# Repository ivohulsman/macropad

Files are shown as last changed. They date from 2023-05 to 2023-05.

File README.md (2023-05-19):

# Macropad V1
A Macropad built with KMK firmware.

**This is a work in progress.**  

### How to install firmware
1. Follow the KMK guide as shown [here](http://kmkfw.io/docs/Getting_Started).
2. Copy the files from /src to your Macropad overwriting existing files.
3. Customize keymaps and OLED to your usecase.

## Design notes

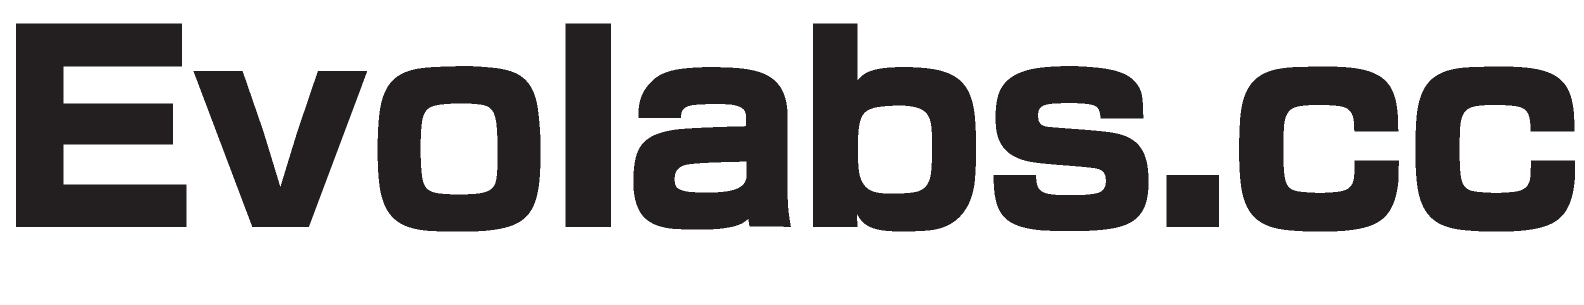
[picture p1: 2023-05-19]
pcb/assets/macropad_evolabs.bmp

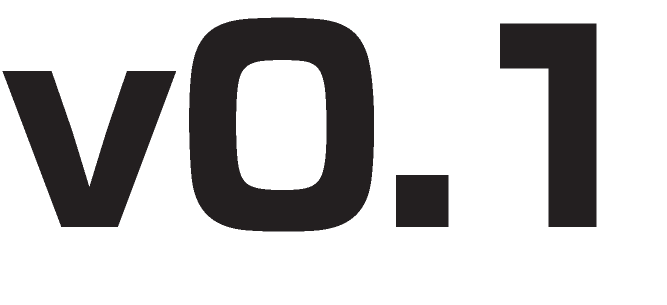
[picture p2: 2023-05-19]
pcb/assets/macropad_version.bmp

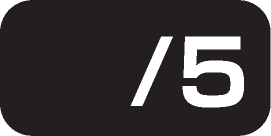
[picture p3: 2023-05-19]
pcb/assets/macropad_sn.bmp

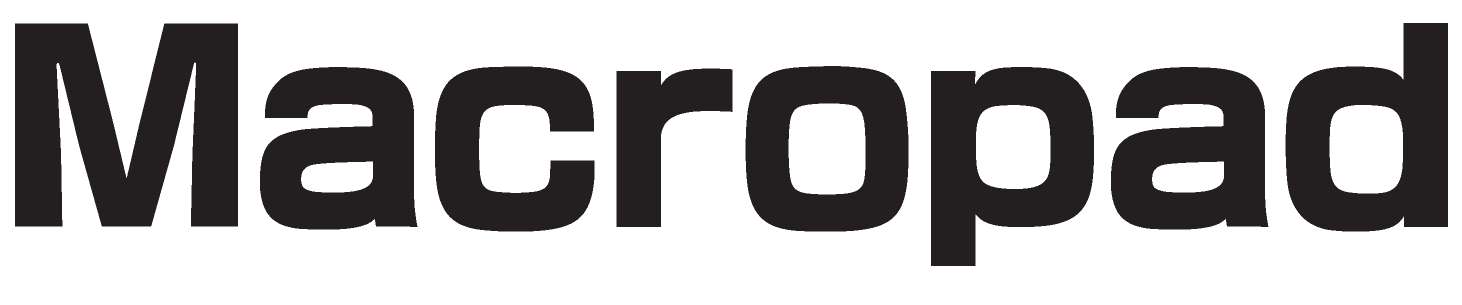
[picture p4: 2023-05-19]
pcb/assets/macropad_v0-1.bmp

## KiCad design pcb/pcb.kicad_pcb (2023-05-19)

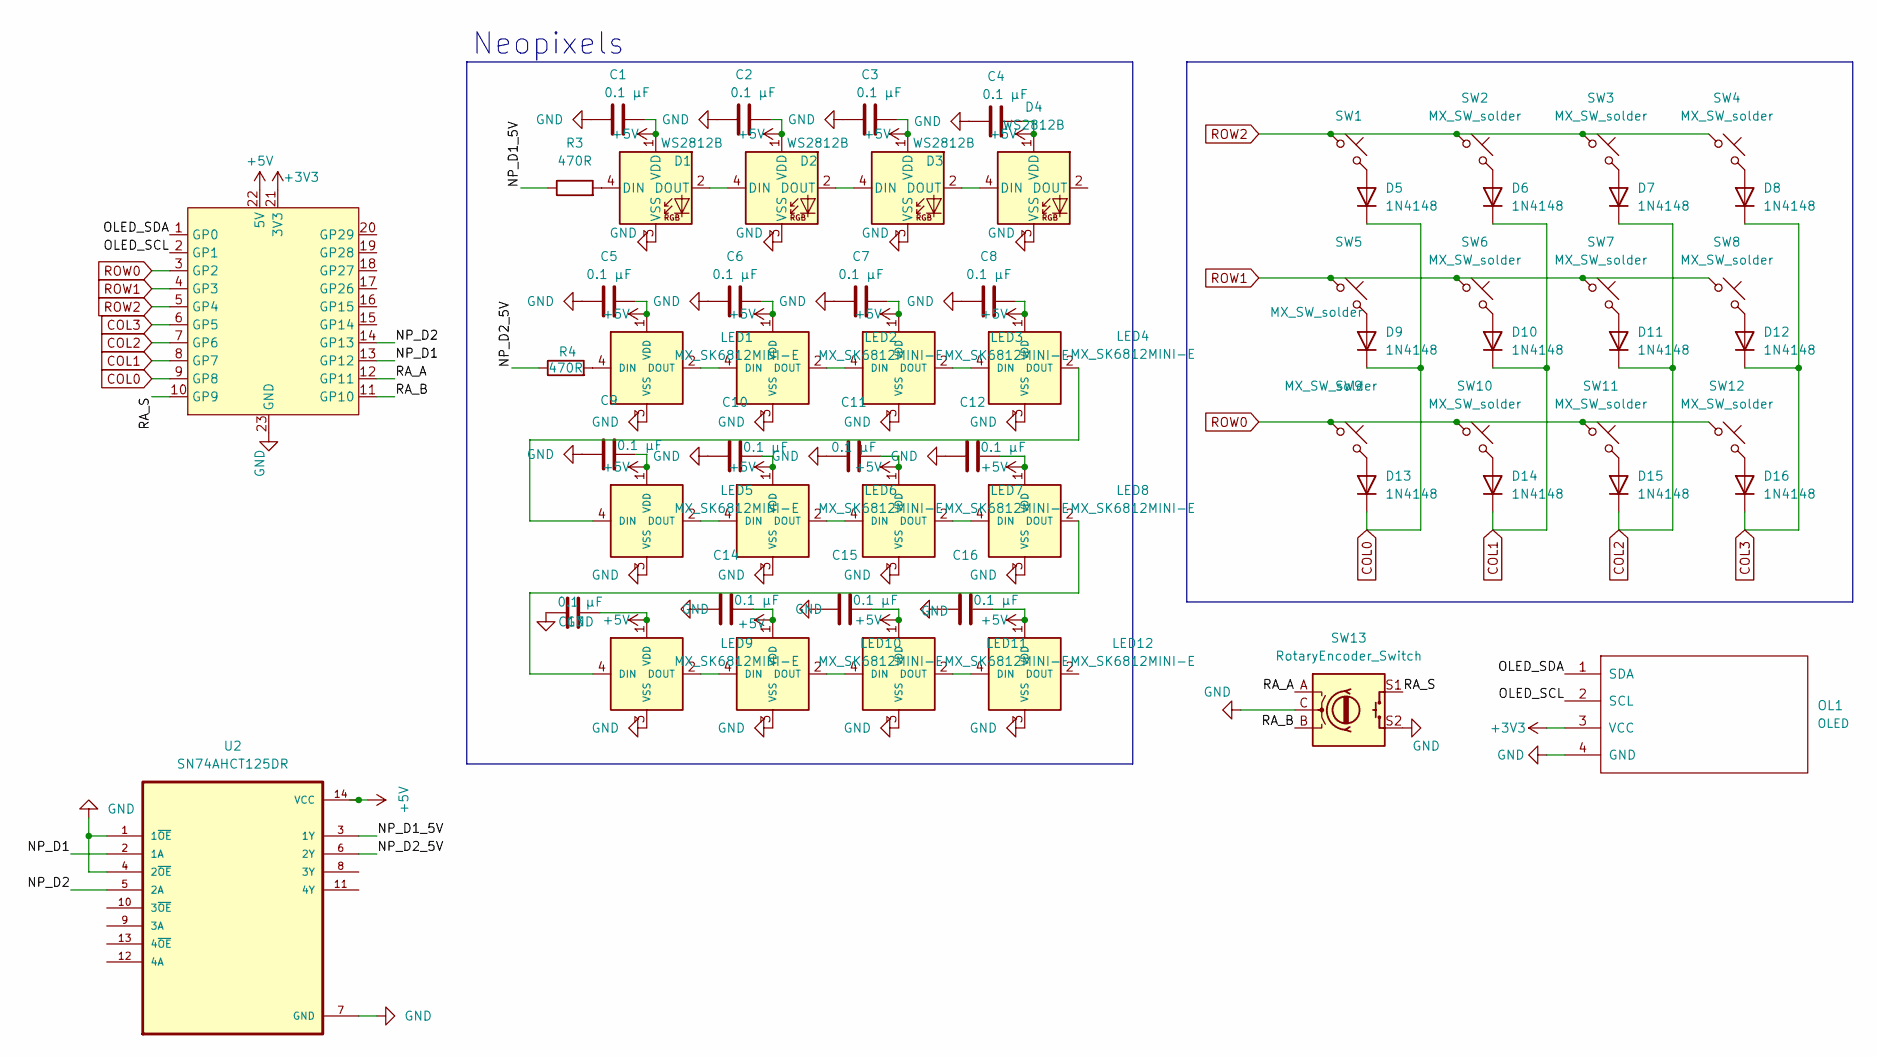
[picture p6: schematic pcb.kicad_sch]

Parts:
C1, C2, C3, C4, C5, C6, C7, C8, C9, C10, C11, C12, C13, C14, C15, C16: 0.1 µF; C_0603_1608Metric
D1, D2, D3, D4: WS2812B; LED_WS2812B_PLCC4_5.0x5.0mm_P3.2mm
D5, D6, D7, D8, D9, D10, D11, D12, D13, D14, D15, D16: 1N4148; D_DO-35_SOD27_P7.62mm_Horizontal
LED1, LED2, LED3, LED4, LED5, LED6, LED7, LED8, LED9, LED10, LED11, LED12: MX_SK6812MINI-E; SK6812-MINI-E
OL1: OLED; SSD1306_0.96_Oled
R3, R4: 470R; R_0603_1608Metric
SW1, SW2, SW3, SW4, SW5, SW6, SW7, SW8, SW9, SW10, SW11, SW12: MX_SW_solder; MX_ALPS_PG1350_noLed
SW13: RotaryEncoder_Switch; RotaryEncoder_EC11
U1: PicoW; RP2040-Zero
U2: SN74AHCT125DR; SOIC127P600X175-14N

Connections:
+3V3: OL1.3 (VCC), U1.21 (3V3)
+5V: C1.2, C2.2, C3.2, C4.2, C5.2, C6.2, C7.2, C8.2, C9.2, C10.2, C11.2, C12.2, C13.2, C14.2, C15.2, C16.2, D1.1 (VDD), D2.1 (VDD), D3.1 (VDD), D4.1 (VDD), LED1.1 (VDD), LED2.1 (VDD), LED3.1 (VDD), LED4.1 (VDD), LED5.1 (VDD), LED6.1 (VDD), LED7.1 (VDD), LED8.1 (VDD), LED9.1 (VDD), LED10.1 (VDD), LED11.1 (VDD), LED12.1 (VDD), U1.22 (5V), U2.14 (VCC)
/NP_D1: U1.13 (GP12), U2.2 (1A)
/NP_D1_5V: R3.1, U2.3 (1Y)
/NP_D2: U1.14 (GP13), U2.5 (2A)
/NP_D2_5V: R4.1, U2.6 (2Y)
/OLED_SCL: OL1.2 (SCL), U1.2 (GP1)
/OLED_SDA: OL1.1 (SDA), U1.1 (GP0)
/RA_A: SW13.A, U1.12 (GP11)
/RA_B: SW13.B, U1.11 (GP10)
/RA_S: SW13.S1, U1.10 (GP9)
COL0: D5.1 (K), D9.1 (K), D13.1 (K), U1.9 (GP8)
COL1: D6.1 (K), D10.1 (K), D14.1 (K), U1.8 (GP7)
COL2: D7.1 (K), D11.1 (K), D15.1 (K), U1.7 (GP6)
COL3: D8.1 (K), D12.1 (K), D16.1 (K), U1.6 (GP5)
GND: C1.1, C2.1, C3.1, C4.1, C5.1, C6.1, C7.1, C8.1, C9.1, C10.1, C11.1, C12.1, C13.1, C14.1, C15.1, C16.1, D1.3 (VSS), D2.3 (VSS), D3.3 (VSS), D4.3 (VSS), LED1.3 (VSS), LED2.3 (VSS), LED3.3 (VSS), LED4.3 (VSS), LED5.3 (VSS), LED6.3 (VSS), LED7.3 (VSS), LED8.3 (VSS), LED9.3 (VSS), LED10.3 (VSS), LED11.3 (VSS), LED12.3 (VSS), OL1.4 (GND), SW13.C, SW13.S2, U1.23 (GND), U2.1 (1~OE), U2.4 (2~OE), U2.7 (GND)
unnamed: D1.4 (DIN), R3.2
unnamed: D1.2 (DOUT), D2.4 (DIN)
unnamed: D2.2 (DOUT), D3.4 (DIN)
unnamed: D3.2 (DOUT), D4.4 (DIN)
unnamed: D5.2 (A), SW1.2
unnamed: D6.2 (A), SW2.2
unnamed: D7.2 (A), SW3.2
unnamed: D8.2 (A), SW4.2
unnamed: D9.2 (A), SW5.2
unnamed: D10.2 (A), SW6.2
unnamed: D11.2 (A), SW7.2
unnamed: D12.2 (A), SW8.2
unnamed: D13.2 (A), SW9.2
unnamed: D14.2 (A), SW10.2
unnamed: D15.2 (A), SW11.2
unnamed: D16.2 (A), SW12.2
unnamed: LED1.4 (DIN), R4.2
unnamed: LED1.2 (DOUT), LED2.4 (DIN)
unnamed: LED2.2 (DOUT), LED3.4 (DIN)
unnamed: LED3.2 (DOUT), LED4.4 (DIN)
unnamed: LED4.2 (DOUT), LED5.4 (DIN)
unnamed: LED5.2 (DOUT), LED6.4 (DIN)
unnamed: LED6.2 (DOUT), LED7.4 (DIN)
unnamed: LED7.2 (DOUT), LED8.4 (DIN)
unnamed: LED8.2 (DOUT), LED9.4 (DIN)
unnamed: LED9.2 (DOUT), LED10.4 (DIN)
unnamed: LED10.2 (DOUT), LED11.4 (DIN)
unnamed: LED11.2 (DOUT), LED12.4 (DIN)
ROW0: SW9.1, SW10.1, SW11.1, SW12.1, U1.3 (GP2)
ROW1: SW5.1, SW6.1, SW7.1, SW8.1, U1.4 (GP3)
ROW2: SW1.1, SW2.1, SW3.1, SW4.1, U1.5 (GP4)

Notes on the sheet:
Neopixels

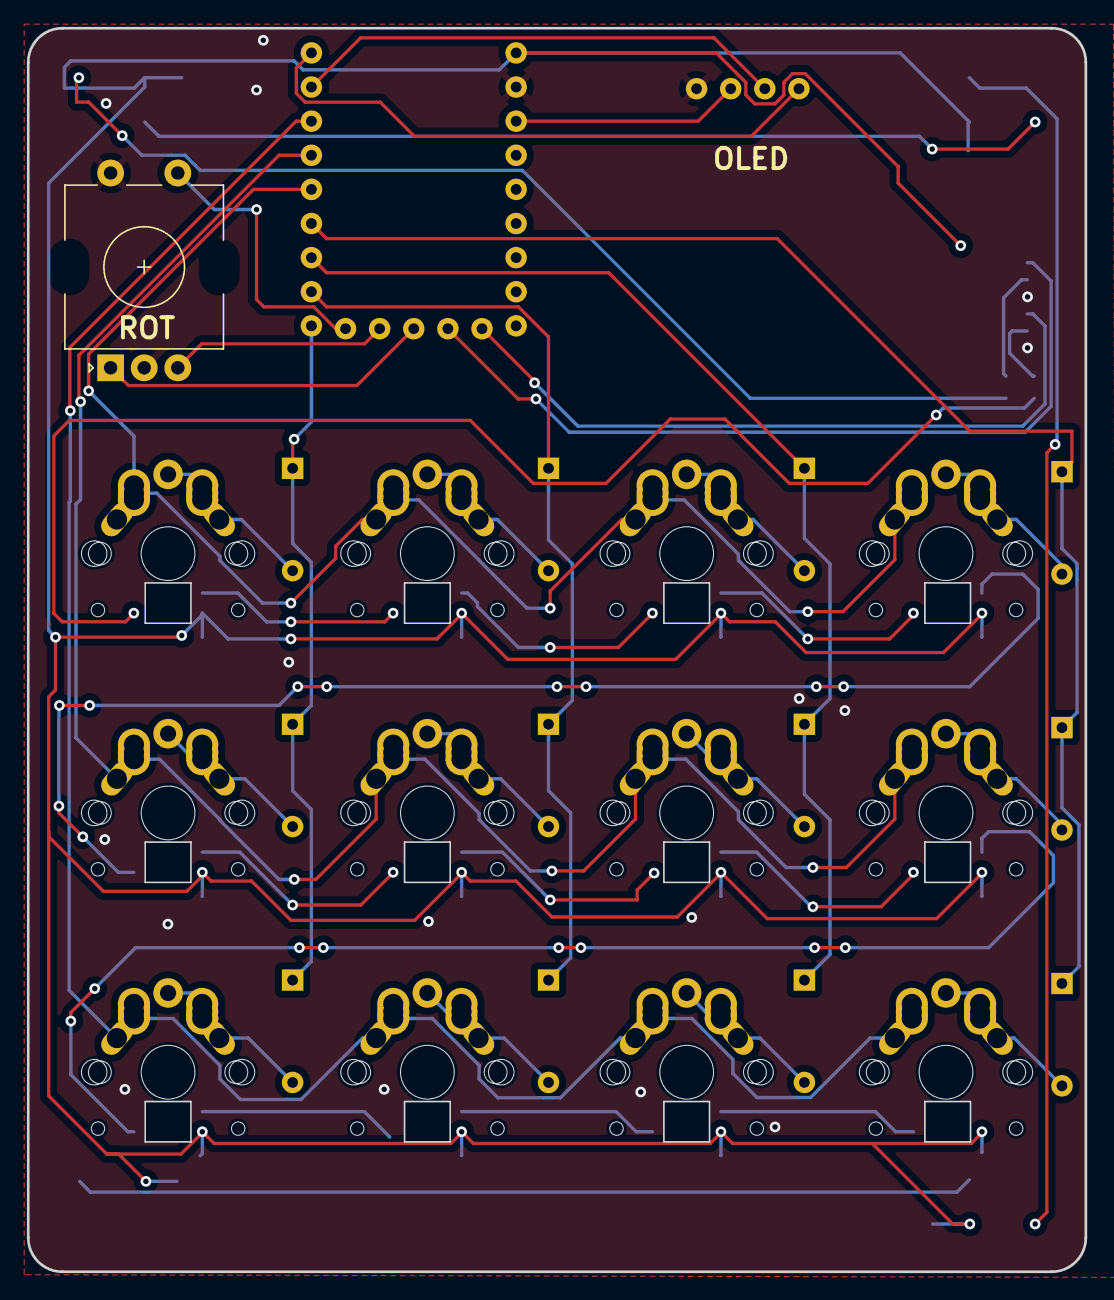
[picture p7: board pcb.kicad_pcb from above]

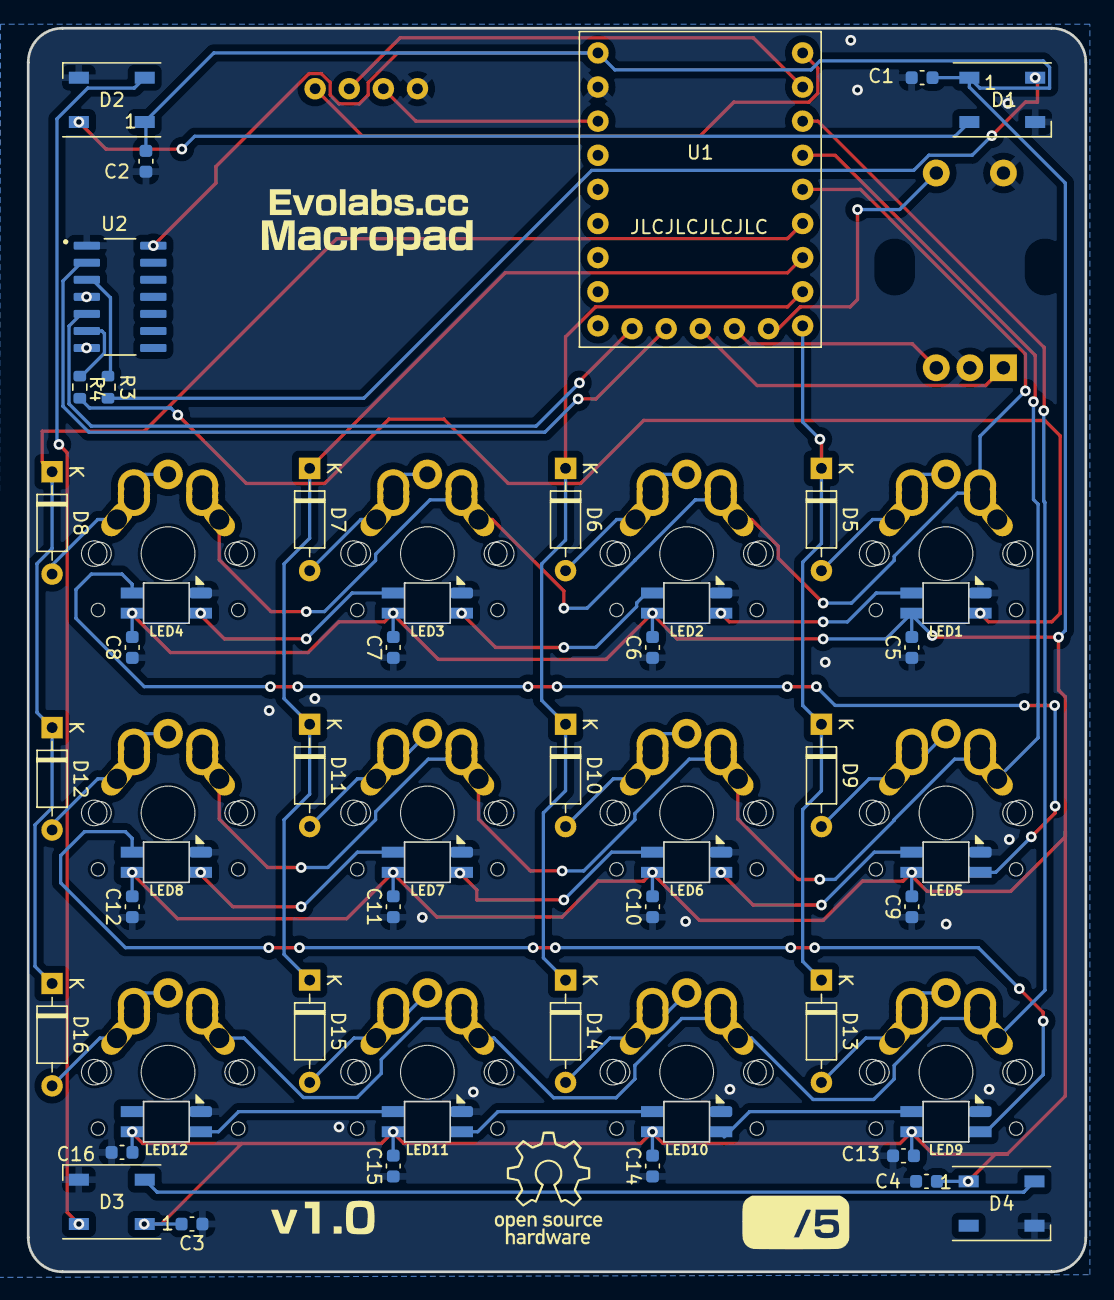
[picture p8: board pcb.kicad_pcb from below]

Board: 2 copper layers, 78.7 x 92.6 mm, 62 parts (49 on the bottom side), 47 nets.

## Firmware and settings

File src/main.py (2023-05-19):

from kb import KMKKeyboard

import supervisor

from kmk.extensions.media_keys import MediaKeys
from kmk.keys import KC
from kmk.modules.encoder import EncoderHandler
from kmk.modules.layers import Layers
from kmk.modules.modtap import ModTap
from kmk.handlers.sequences import simple_key_sequence


# Disable hot reloading on save
supervisor.runtime.autoreload = True


keyboard = KMKKeyboard()
layers = Layers()
modtap = ModTap()

# Debug mode
keyboard.debug_enabled = False

# Append extensions to KMK
keyboard.extensions.append(keyboard.rgb)
keyboard.extensions.append(MediaKeys())
keyboard.extensions.append(keyboard.oled)


# Init Rotary Encoder
encoder_handler = EncoderHandler()
encoder_handler.pins = (
    (keyboard.rot_a_pin, keyboard.rot_b_pin,
     keyboard.rot_bt_pin, False, 4),  # encoder #1
)

keyboard.modules = [layers, encoder_handler, modtap]

# Define layers
LYR_NOR, LYR_RGB, LYR_MOD = 0, 1, 2

# Define custom keys
MOD_OR_NORM = KC.MT(KC.TO(LYR_NOR), KC.MO(LYR_MOD))

# Save VIM macro
VIM_WBUF = simple_key_sequence(
    (
        KC.ESC,
        KC.COLN,
        KC.W,
        KC.ENTER,
    )
)

# Define Keymaps
keyboard.keymap = [
    [
        # Normal Layer
        KC.A, KC.B, KC.C, KC.D,
        VIM_WBUF, KC.F, KC.G, KC.H,
        KC.I, KC.J, KC.K, MOD_OR_NORM,
    ],
    [
        # RGB Layer
        KC.RGB_VAI, KC.RGB_VAD, KC.RGB_HUI, KC.RGB_HUD,
        KC.RGB_SAI, KC.RGB_SAD, KC.RGB_MODE_PLAIN, KC.RGB_MODE_BREATHE,
        KC.RGB_MODE_RAINBOW, KC.RGB_MODE_BREATHE_RAINBOW, KC.RGB_MODE_SWIRL, KC.MO(
            LYR_MOD),
    ],
    [
        # Mode Layer
        KC.TO(LYR_NOR), KC.B, KC.C, KC.D,
        KC.E, KC.F, KC.G, KC.H,
        KC.TO(LYR_RGB), KC.J, KC.RELOAD, KC.L,
    ]
]

# Define Rotary Encoder Keymaps
encoder_handler.map = [((KC.VOLD, KC.VOLU, KC.MUTE),),  # Standard
                                ((KC.VOLD, KC.VOLU, KC.MUTE),),  # Extra
                                ]

if __name__ == '__main__':
    keyboard.go()

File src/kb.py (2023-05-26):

import os
import board
import busio 
import neopixel

from kmk.kmk_keyboard import KMKKeyboard as _KMKKeyboard
from kmk.scanners import DiodeOrientation
from kmk.extensions.rgb import RGB
from kmk.extensions.oled import Oled, TextEntry, ImageEntry # New OLED extension


class KMKKeyboard(_KMKKeyboard):
    col_pins = (
        board.GP8,
        board.GP7,
        board.GP6,
        board.GP5,
    )

    row_pins = (
        board.GP4,
        board.GP3,
        board.GP2,
    )

    diode_orientation = DiodeOrientation.ROWS

    bl_pin = board.GP13
    ug_pin = board.GP12

    rot_a_pin = board.GP10
    rot_b_pin = board.GP11
    rot_bt_pin = board.GP9

    SCL = board.GP1
    SDA = board.GP0

# Init RGB
    pixels = (
        neopixel.NeoPixel(bl_pin, 12,),
        neopixel.NeoPixel(ug_pin, 4,)
    )

    rgb = RGB(pixel_pin=None, pixels=pixels,
              hue_default=os.getenv("RGB_HUE"),
              sat_default=os.getenv("RGB_SAT"),
              val_default=os.getenv("RGB_BOOT_VAL"),
              val_limit=os.getenv("RGB_VAL"),
              val_step=36)

    oled = Oled(
        entries=[
            TextEntry(text='my', x=128, y=0, x_anchor='R'),
            TextEntry(text='keyboard', x=128, y=10, x_anchor='R'),
            TextEntry(text='left', x=128, y=20, x_anchor='R', side='L'),
            TextEntry(text='right', x=128, y=20, x_anchor='R', side='R'),
            TextEntry(text='Layer: ', x=0, y=32, y_anchor='B'),
            TextEntry(text='BASE', x=40, y=32, y_anchor='B', layer=0),
            TextEntry(text='LOWER', x=40, y=32, y_anchor='B', layer=1),
            TextEntry(text='RAISE', x=40, y=32, y_anchor='B', layer=2),
            TextEntry(text='RGB', x=40, y=32, y_anchor='B', layer=3),
            TextEntry(text='SETTINGS', x=40, y=32, y_anchor='B', layer=4),
            TextEntry(text='0 1 2 3 4', x=0, y=4),
            TextEntry(text='0', x=0, y=4, inverted=True, layer=0),
            TextEntry(text='1', x=12, y=4, inverted=True, layer=1),
            TextEntry(text='2', x=24, y=4, inverted=True, layer=2),
            TextEntry(text='3', x=36, y=4, inverted=True, layer=3),
            TextEntry(text='4', x=48, y=4, inverted=True, layer=4),
        ],
        i2c=busio.I2C(SCL, SDA),
        device_address=0x3C,
        width=128,
        height=64,
        flip=False,
        flip_left=False,
        flip_right=True,
        dim_time=10,
        dim_target=0.1,
        off_time=30,
        powersave_dim_time=5,
        powersave_dim_target=0.1,
        powersave_off_time=120,
        brightness=1,
        brightness_step=0.1,
    )
